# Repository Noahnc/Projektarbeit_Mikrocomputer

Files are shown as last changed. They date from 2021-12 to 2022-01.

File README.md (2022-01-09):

# Projektarbeit Mikrocomputertechnik

In dieser Repository ist sämtlicher Source Code, SQL Statements, Backups und Dokumentationen des Mikrocompuetertechnik-Projekts "Wetterstation".

Grafana Dashboard:
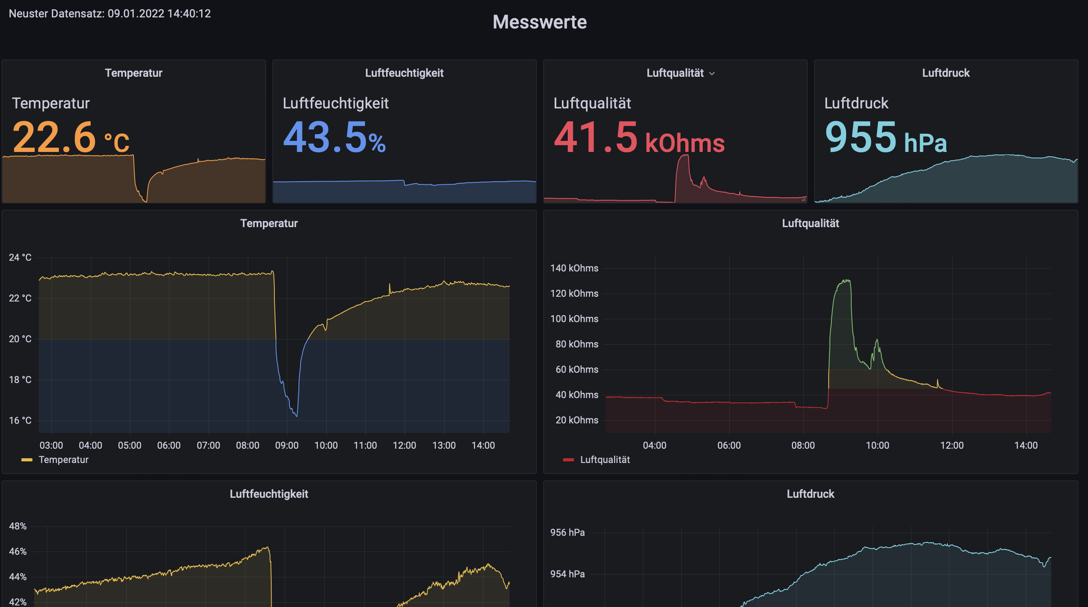
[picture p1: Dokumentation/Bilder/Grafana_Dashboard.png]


Nodered Dashboard:
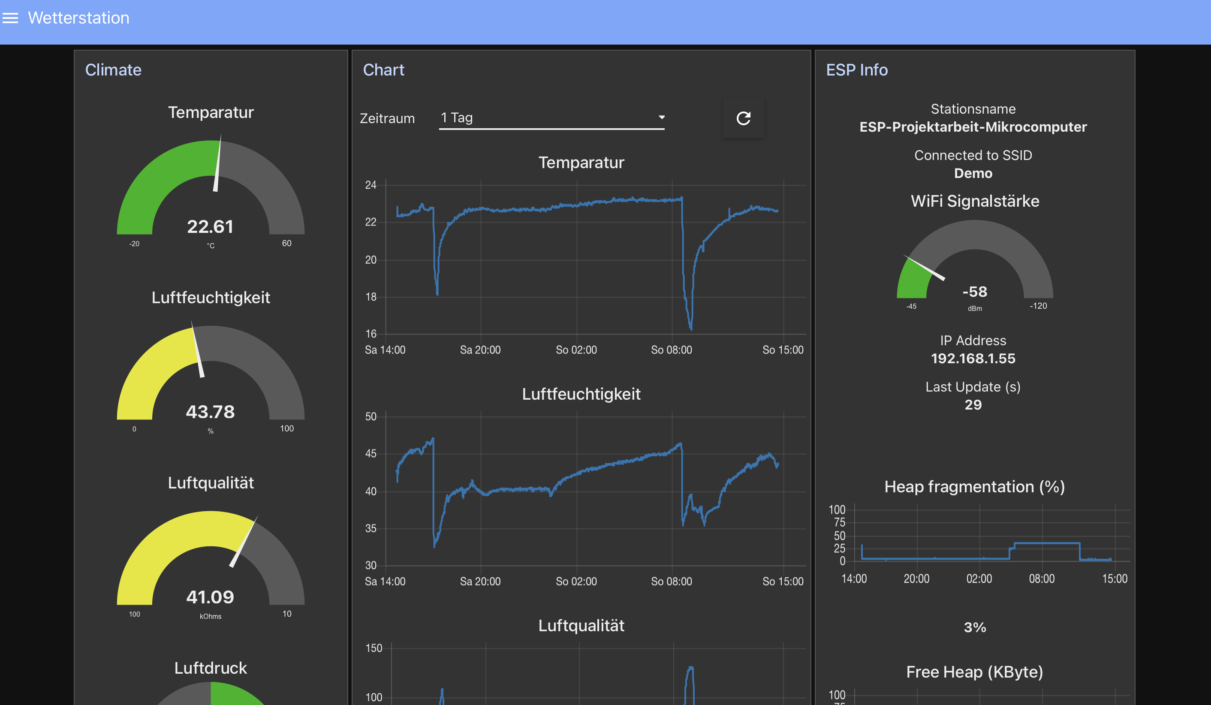
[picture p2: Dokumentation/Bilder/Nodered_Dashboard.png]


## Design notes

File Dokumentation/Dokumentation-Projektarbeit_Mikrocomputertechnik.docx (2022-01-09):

Dokumentation Wetterstation

Projektbezeichnung | Projektarbeit Mikrocomputertechnik
Projektleiter | Noah Canadea / Milan Bursac
Erstellt am | 20.12.2021
Letzte Änderung am | 10.01.2022
Status | abgeschlossen
Aktuelle Version | 1.0

Änderungsverlauf

Nr. | Datum | Version | Geänderte Kapitel | Art der Änderung | Autor | Status
1 | 20.12.2021 | 0.5 | Alle | Erstellung | Noah Canadea | ok
2 | 03.01.2022 | 0.6 | 6, 7, 8 | Ergänzung | Noah Canadea | Ok
3 | 08.01.2022 | 0.7 | Alle | Anpassungen | Noah Canadea | Ok
4 | 09.01.2022 | 1 | Alle | Anpassungen und Ergänzungen | Milan Bursac | Ok

# 1 Schemas

## 1.1 Elektronik Schema ESP (Wetterstation)

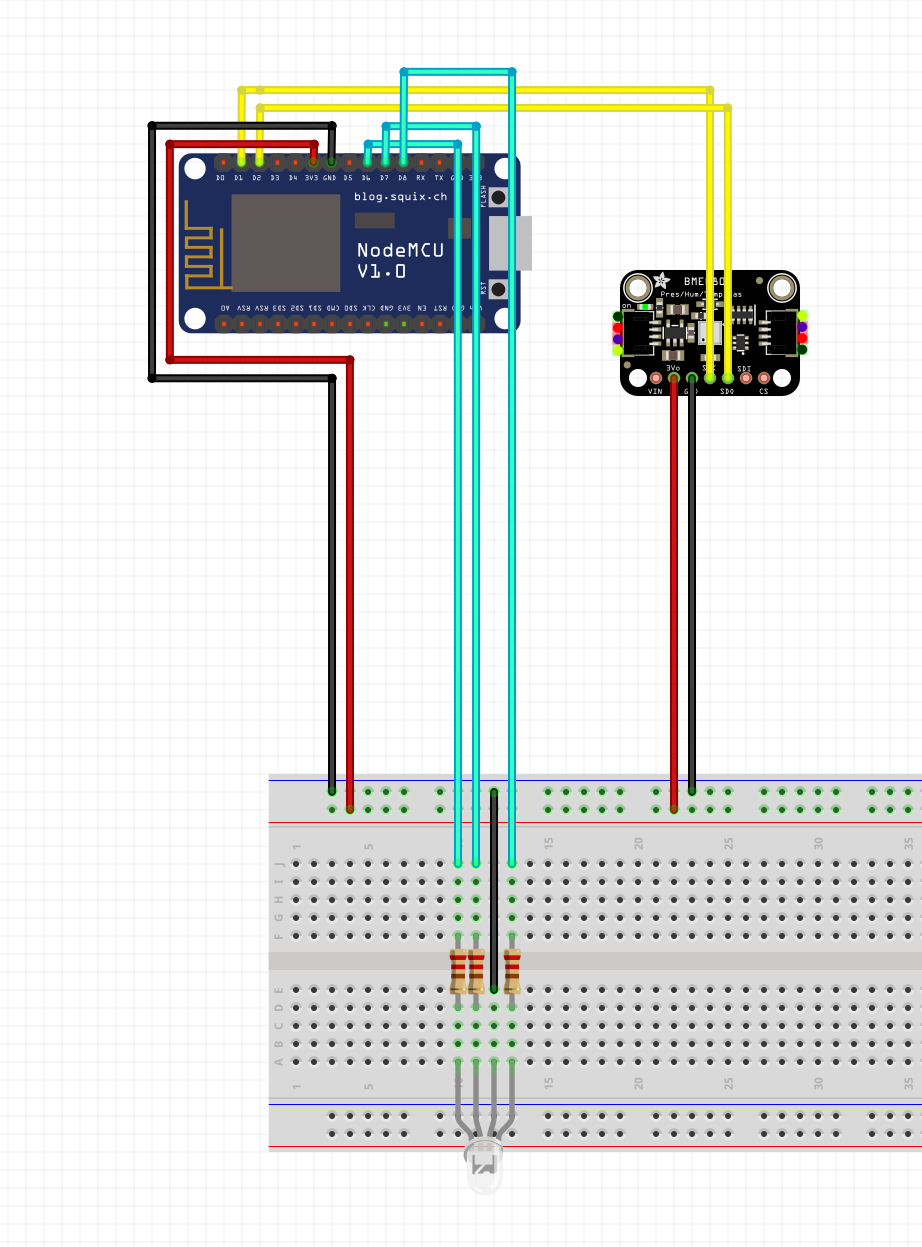
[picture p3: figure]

## 1.2 Aktivitätsdiagramme

### 1.2.1 ESP Code (Wetterstation)

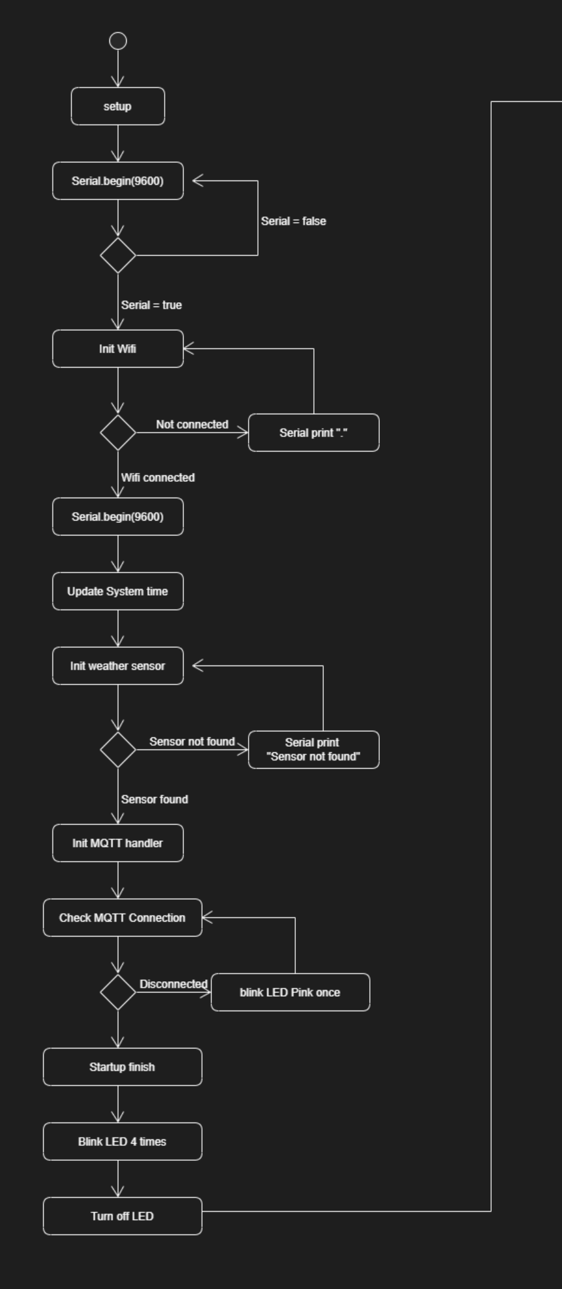
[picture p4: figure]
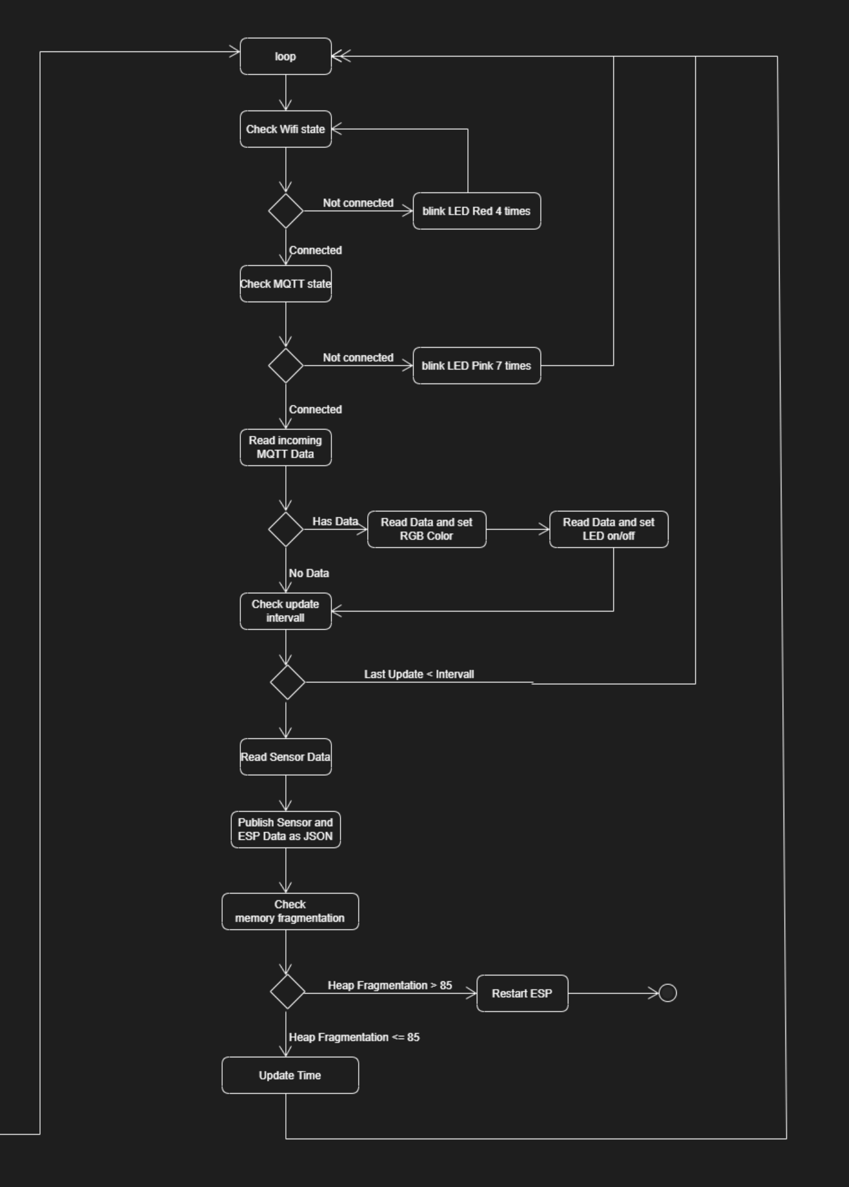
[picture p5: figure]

### 1.2.2 NodeRed (Backend)

Live Data Handler

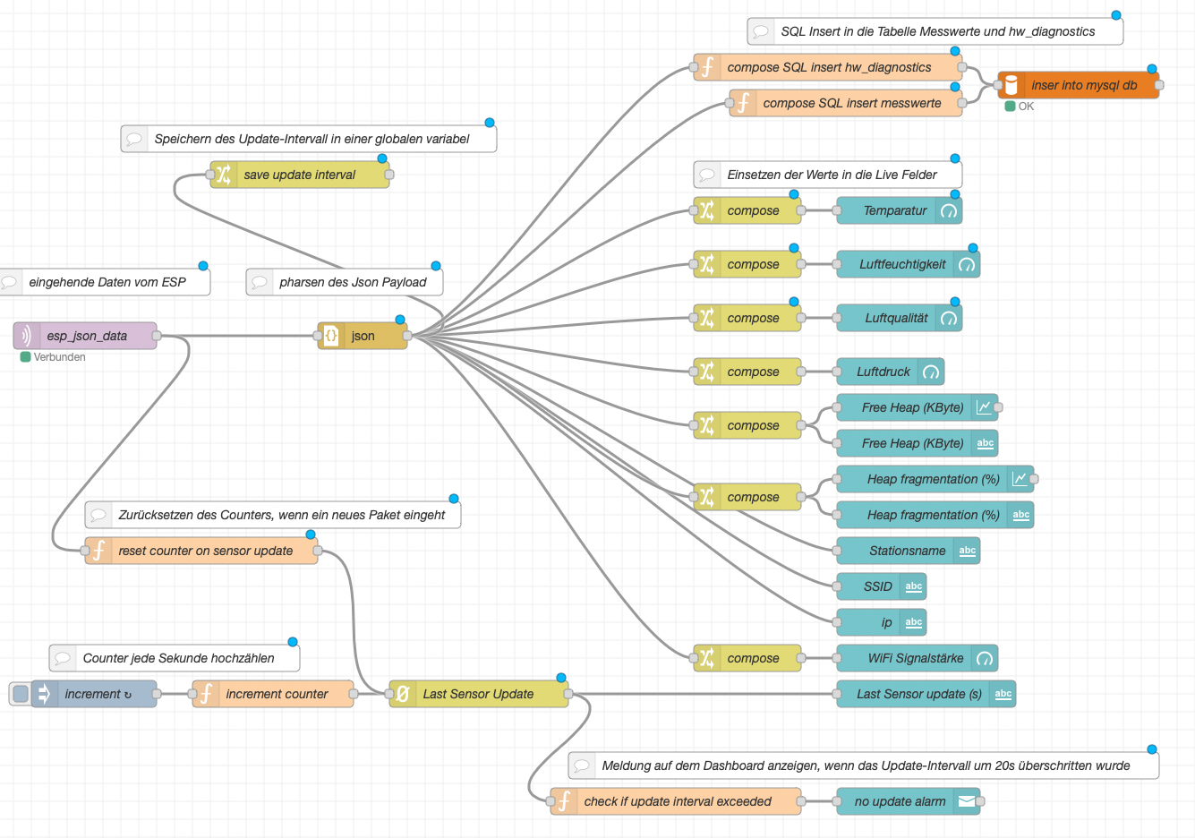
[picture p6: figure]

Hystory Data Handler

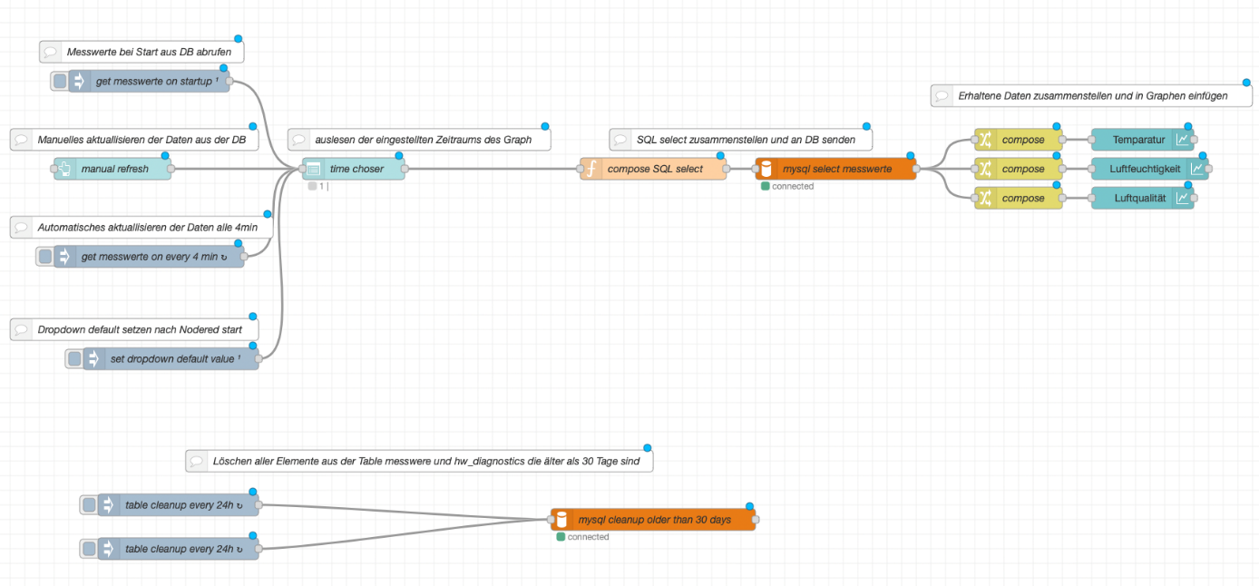
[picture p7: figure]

## 1.3 MySQL Schema

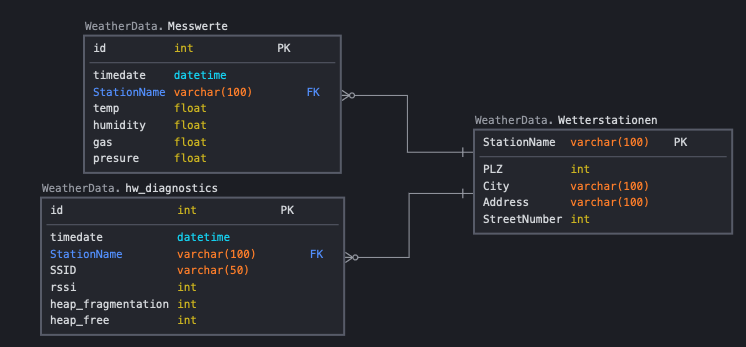
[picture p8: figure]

## 1.4 Prinzipschema Cloud

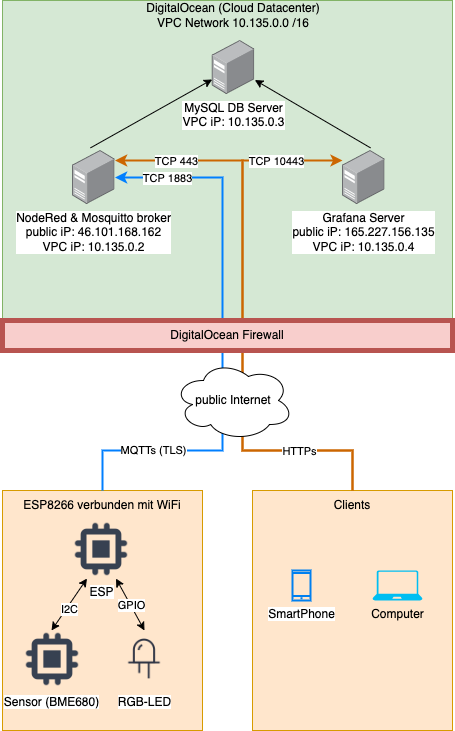
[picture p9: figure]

# 2 Soll – Ist Abgleich

Soll | Ist | Erfüllt
4.1 Erheben folgender Messwerte: - Temperatur - Luftfeuchtigkeit - Luftqualität - Luftdruck | Temperatur, Luftfeuchtigkeit, Luftqualität und Luftdruck werden aufgezeichnet. | JA
4.2 Erheben diverser Metriken der Wetterstation: - iP Adresse - Hostname - Systemzustand - Letztes Update der Station usw. | Die Station sendet diverse Metadaten an den NodeRed Server: - Hostname - Verbundene SSID - WiFi Stärke in RSSI - iP Adresse - Heap Fragmentierung - Freier Heap Speicher | JA
4.3 Persistente Speicherung der Messwerte in der Cloud: Sämtliche, aufgezeichneten Messwerte sollen auf einem zentralen Server in der Cloud für einen definierten Zeitraum gespeichert werden. Hierzu soll eine DB wie Bspw. MySQL verwendet werden, auf welche zu einem späteren Zeitpunkt weitere Systeme für die Auswertung angebunden werden können. | Die Messwerte werden von der Wetterstation als JSON Payload per MQTTs an den NodeRed gesendet. Dieser speichert die Werte anschließend in einem MySQL Server. | JA
4.4 Fehlererkennung: Die Wetterstation soll die Möglichkeit haben, im Falle eines Fehlers (Server Verbindung getrennt, keine Netzwerkverbindung usw.), dies mithilfe einer LED oder eines Displays zu signalisieren. | Verliert die Station die MQTT oder WLAN-Verbindung, wird dies mittels einer RGB LED signalisiert. Je nach Fehler, wird eine andere Farbe verwendet: Rot blinkend: Kein WLAN. Orange blinkend: MQTT Fehler | JA
5.1 Technologien Für die Entwicklung sollen Produkte und Technologien nach aktuellem Stand der Technik eingesetzt werden. Gibt es für eine spezifische Anforderung bereits eine Library, kann diese sofern ausgewiesen verwendet werden. | Sämtlicher Code wurde nach bestem Wissen und Stand der Technik entwickelt. Die verwendeten Module können im Punkt 3 dieses Dokuments entnommen werden. | JA
5.2 Sicherheit Sämtliche Systeme sollen nach aktuellem Stand der Technik abgesichert werden. Verbindungen, welche über das Internet aufgebaut werden, müssen mit Hilfe von SSL/TLS und gültigen Zertifikaten verschlüsselt werden, um ein Mitlesen oder Manipulieren der Daten seitens Dritter zu erschweren. | Das NodeRed UI und Grafana sind über HTTPs mit einem gültiges SSL Zertifikat gesichert. Sämtliche MQTT Kommunikation zwischen Wetterstation und NodeRed (Mosquitto) ist per TLS gesichert. Lediglich mit der Zertifikatsprüfung gibt es noch Probleme, weshalb diese zum aktuellen Zeitpunkt deaktiviert ist. | Teilweise
5.3 Hosting Weil der Kunde die Server nicht lokal betreiben möchte, sollen diese bei einem großen Cloud-Provider gehostet werden. Die Auswahl des Anbieters ist hierbei dem Entwickler überlassen. | Der MySQL Server, Grafana Server und Node-Red Server werden als separate Ubuntu VMs bei DigitalOcean gehostet. | JA
5.4 Erweiterbarkeit Um Erweiterungen zu einem späteren Zeitpunkt zu ermöglichen, müssen sämtliche Software-Module möglichst modular und erweiterbar konzipiert werden. | Der Source-Code der Wetterstation wurde möglichst modular aufgebaut. Für verschiedene Aufgaben wurden eigene Klassen erstellt (Bspw. für das MQTT Handling). Die DB wurde so konzipiert, dass mehrere Wetterstationen gleichzeitig Daten aufzeichnen können. | JA

# 3 Testprotokoll

Test | Erwartetes Ergebnis | Tatsächliches Ergebnis | Erfüllt
Simulieren einer fehlenden WLAN-Verbindung der Wetterstation. | Die LED Blinkt einige Male Rot und pausiert anschliessend. Dies geschieht so lange, bis die WLAN-Verbindung wieder aufgebaut ist. | Die LED Blinkt einige Male Rot und pausiert anschliessend. Dies geschieht so lange, bis die WLAN-Verbindung wieder aufgebaut ist. | Ja
Simulieren einer fehlenden MQTT-Verbindung der Wetterstation. | Die LED Blinkt einige Male Violett und pausiert anschliessend. Dies geschieht so lange, bis die MQTT-Verbindung wieder aufgebaut ist. Auf dem NodeRed Dashboard sollte nach überschreiten des Updateintervall um 20s eine Meldung erscheinen, dass die Station offline ist. | Die LED Blinkt einige Male Violett und pausiert anschliessend. Dies passierte so lange, bis die MQTT-Verbindung wieder hergestellt wurde. Auf dem NodeRed Dashboard ist nach 50s eine Warnmeldung erschienen, dass die Station keine Daten mehr sendet. | Ja
Betreiben der Station für einen längeren Zeitraum, um sicherzustellen, dass diese Stabil läuft. | Die Station sollte ohne Probleme über einen längeren Zeitraum betrieben werden können. Die aufgezeichneten Daten werden hierbei mit dem definierten Updateintervall an den NodeRed gesendet. | Die Station ist Stand 08.01.2022 seit über einer Woche kontinuierlich in Betrieb. Bis jetzt konnten keine Probleme festgestellt werden. Auch das Updateintervall wird zeitlich eingehalten. | Ja
Validieren der Genauigkeit der Messdaten. | Die von der Wetterstation gesammelten Daten sollten relativ genau sein. | Wir haben die vom BME 680 Sensor aufgezeichneten Daten mit einem anderen Produkt (Netatmo) abgeglichen. Die Messwerte sind hierbei ziemlich genau. Bei der Temperatur beträgt der Unterschied Bspw. höchstens 0.2 – 0.4°C. | JA

# 4 Zeitplan

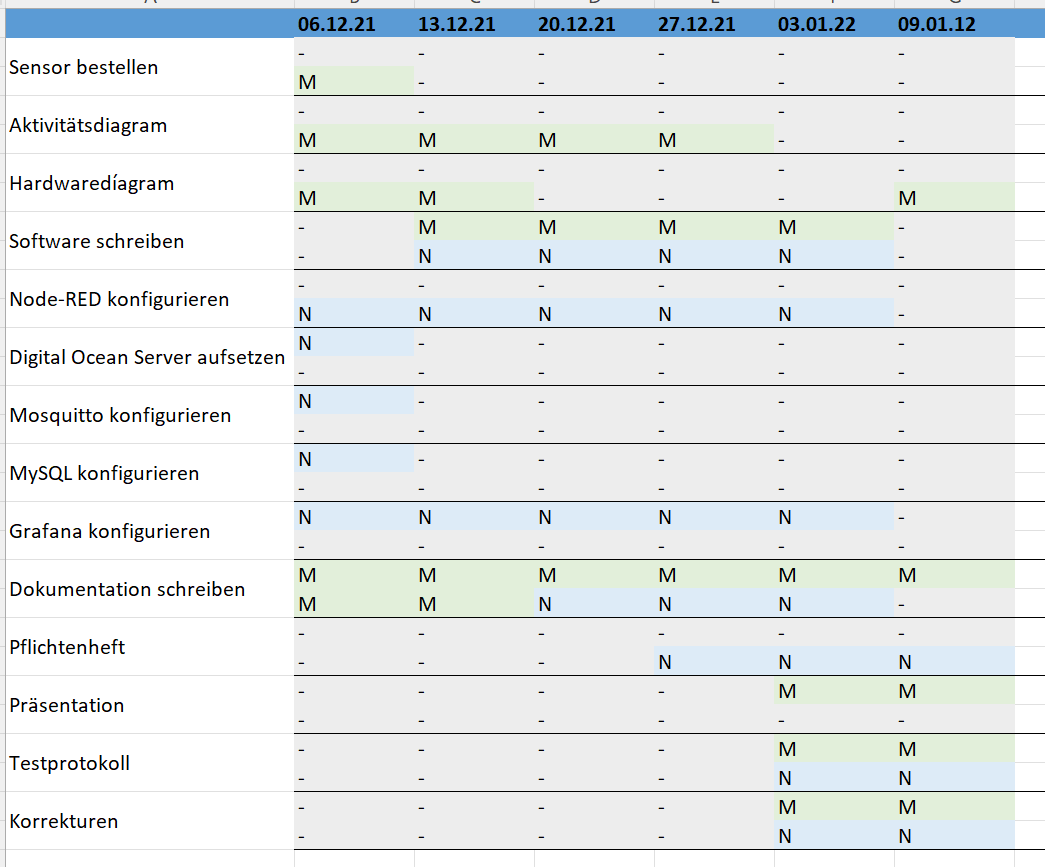
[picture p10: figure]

# 5 Verwendete Produkte und Librarys

## 5.1 Backend / Frontend

- Node-Red (https://nodered.org/): Backend und Frontend UI.
  - Node-red-dashboard (https://flows.nodered.org/node/node-red-dashboard): Diverse UI Elemente.
  - Node-red-node-mysql (https://flows.nodered.org/node/node-red-node-mysql): Verbindungen zum MySQL Server.
  - Node-red-contrib-counter (https://flows.nodered.org/node/node-red-contrib-counter): Baustein welcher einen Counter ausgibt.
- MySQL (https://www.mysql.com/de/): DB Server zur Speicherung der Messwerte.
- Grafana (https://grafana.com/): Visualisierung der MySQL Daten.
  - DynamicText (https://grafana.com/grafana/plugins/marcusolsson-dynamictext-panel/): Modul zur darstellung von dynamischem Text basierend auf SQL Querys.

## 5.2 ESP8266 Wetterstation Librarys

- Adafruit BME680 (https://github.com/adafruit/Adafruit_BME680): Library zum Auslesen der Sensorwerte.
- ESP8266WiFi (https://github.com/esp8266/Arduino/tree/master/libraries/ESP8266WiFi): Library für WLAN und TLS Verbindungen.
- PubSubCLient (https://github.com/knolleary/pubsubclient): Library für MQTT Verbindungen zwischen Node-Red und Wetterstation.
- NTPClient (https://github.com/arduino-libraries/NTPClient): Library für Zeitsync per NTP.
- ArduinoJson (https://github.com/bblanchon/ArduinoJson): Library zum parsen von Daten zu Json Objekten.

## 5.3 ESP8266 Wetterstation Hardware

- NodeMCU ESP8266 (https://www.make-it.ca/nodemcu-details-specifications/): Hauptmodul
- RGB LED (https://components101.com/diodes/rgb-led-pinout-configuration-circuit-datasheet): Status LED
- BME 680 (https://www.bosch-sensortec.com/media/boschsensortec/downloads/datasheets/bst-bme680-ds001.pdf): Wettersensor

# 6 Dashboards Links

- Grafana Dashboard (https://grafana-projektarbeit-mikrocomputer.canadea.ch:10443/d/L2wuqYA7k/wetterstationen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)
- Node-Red Dashboard (https://projektarbeit-mikrocomputer.canadea.ch/ui/)

# 7 Anhang

- Plattform IO Projekt der Wetterstation
- NodeRed Konfiguration
- Grafana Konfiguration
- SQL Statements zur Erstellung der DB
- Pflichtenheft

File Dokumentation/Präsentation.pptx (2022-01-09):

## Abschlussprojekt

Noah & Milan

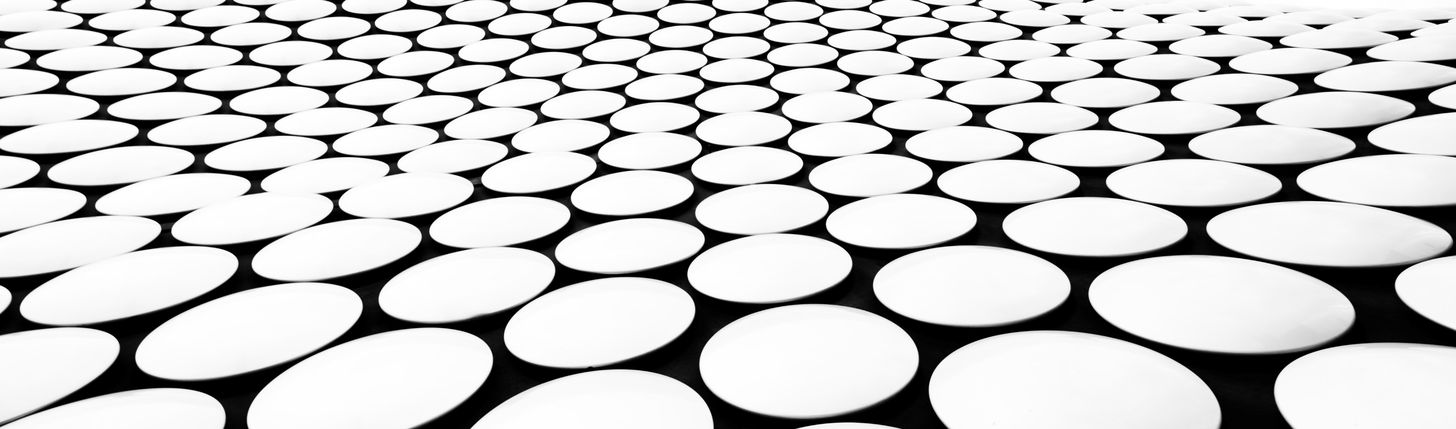
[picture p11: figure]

## Unser Projekt

- Sensordaten (Luftfeuchtigkeit, Temperatur, Luftqualität und Luftdruck) und ESP-Informationen (wie WLAN, Temperatur, Memory, etc.) auf einen Node-RED sowie Grafana Server publishen.
- RGB LED-Steuerung über einen Node-RED Server.

## Aufbau

## Komponenten

1. ESP8266 WiFi
2. BME680 (Sensor)
3. RGB LED
4. 3 Server bei DigitalOcean (Cloud)
5. GitHub für Versioning
6. Teams für Dateiablage

## Prinzipschema


## Fritzing Schema


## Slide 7

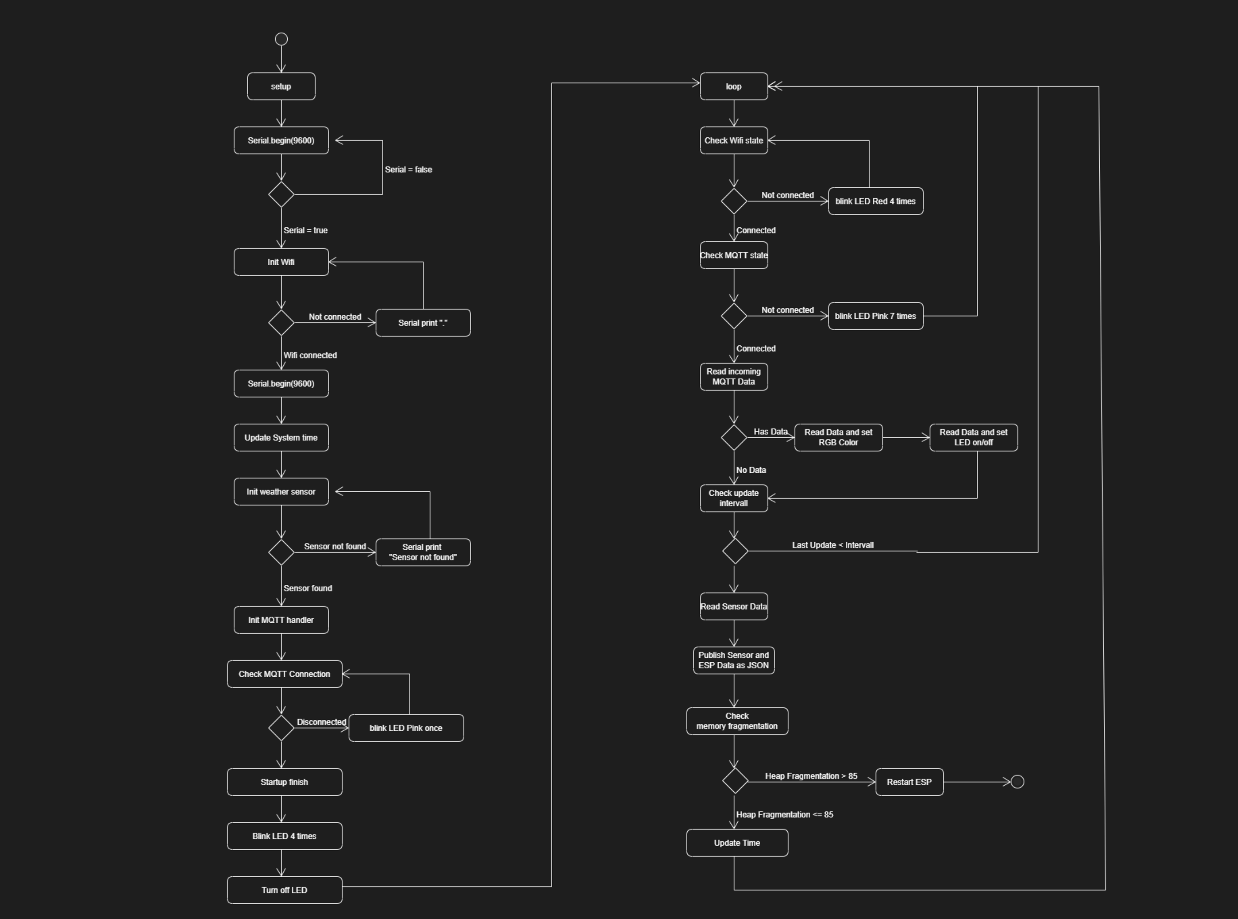
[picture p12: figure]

## MYSQL Schema


## Node-Red: Live-Data Handler

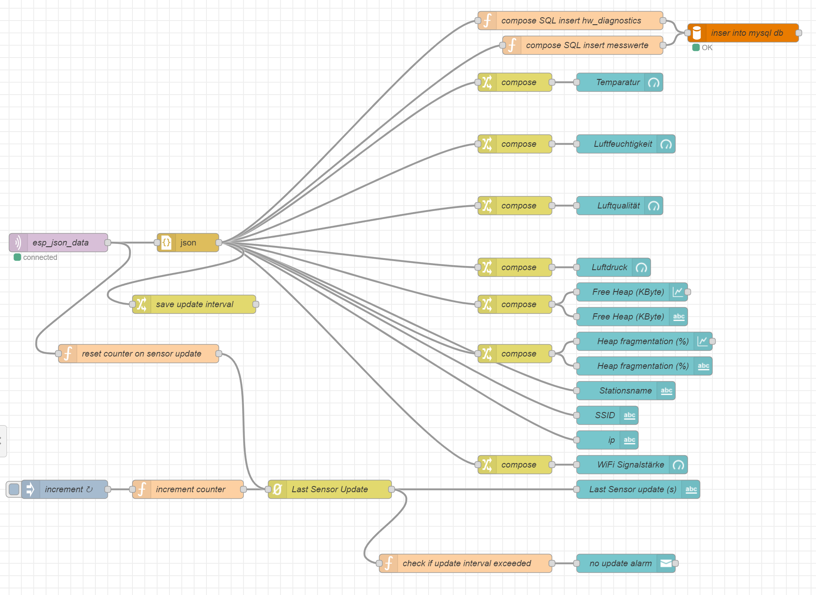
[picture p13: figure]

## Node-Red: History-Data Handler

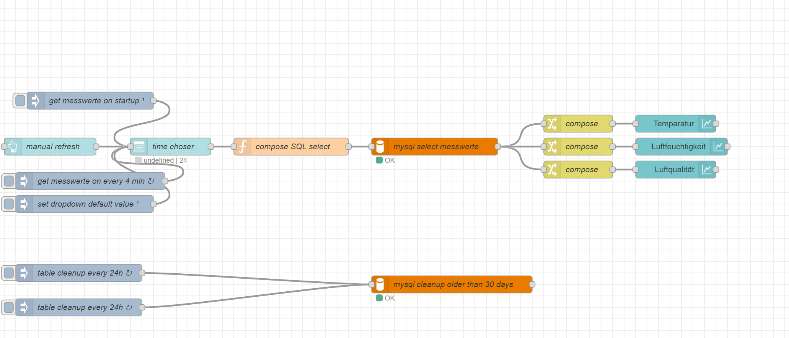
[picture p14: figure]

## Node-Red: LED Handler

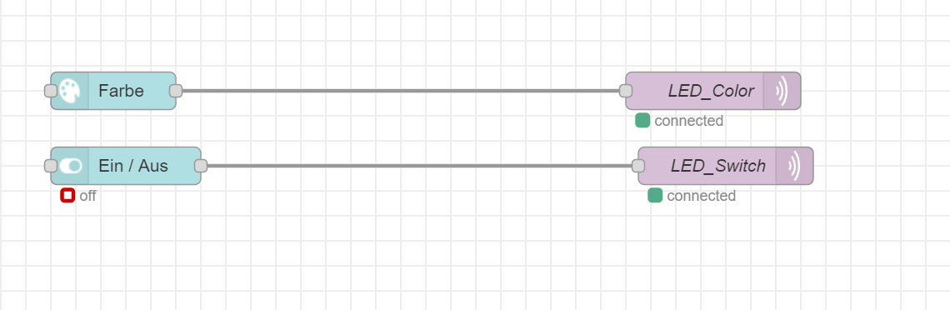
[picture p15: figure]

## Resultat

## Node-Red: RGB LED STeuerung

- Wetterstation Dashboard (canadea.ch) (https://projektarbeit-mikrocomputer.canadea.ch/ui/#!/1?socketid=QfBu8go3oNbt1V-KAAKL)

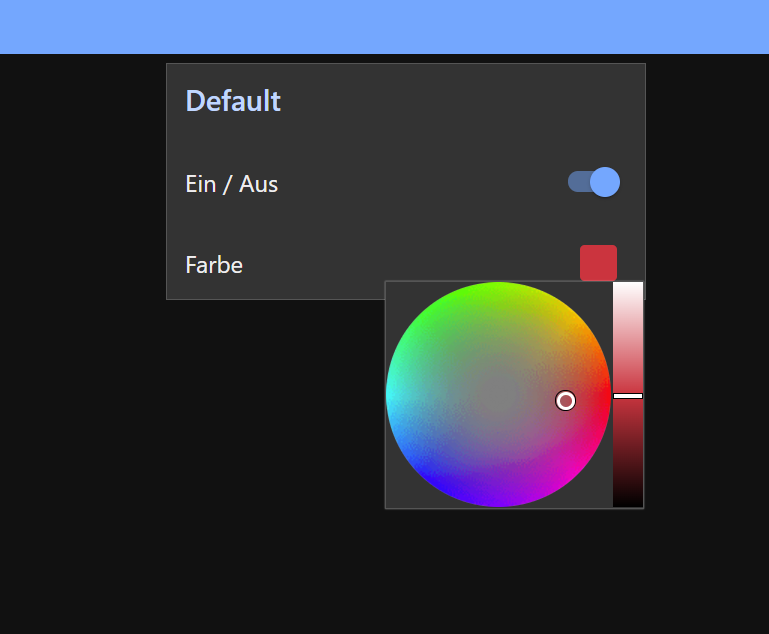
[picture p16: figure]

## Node-red: Sensordaten

- Wetterstation Dashboard (canadea.ch) (https://projektarbeit-mikrocomputer.canadea.ch/ui/#!/0?socketid=QfBu8go3oNbt1V-KAAKL)

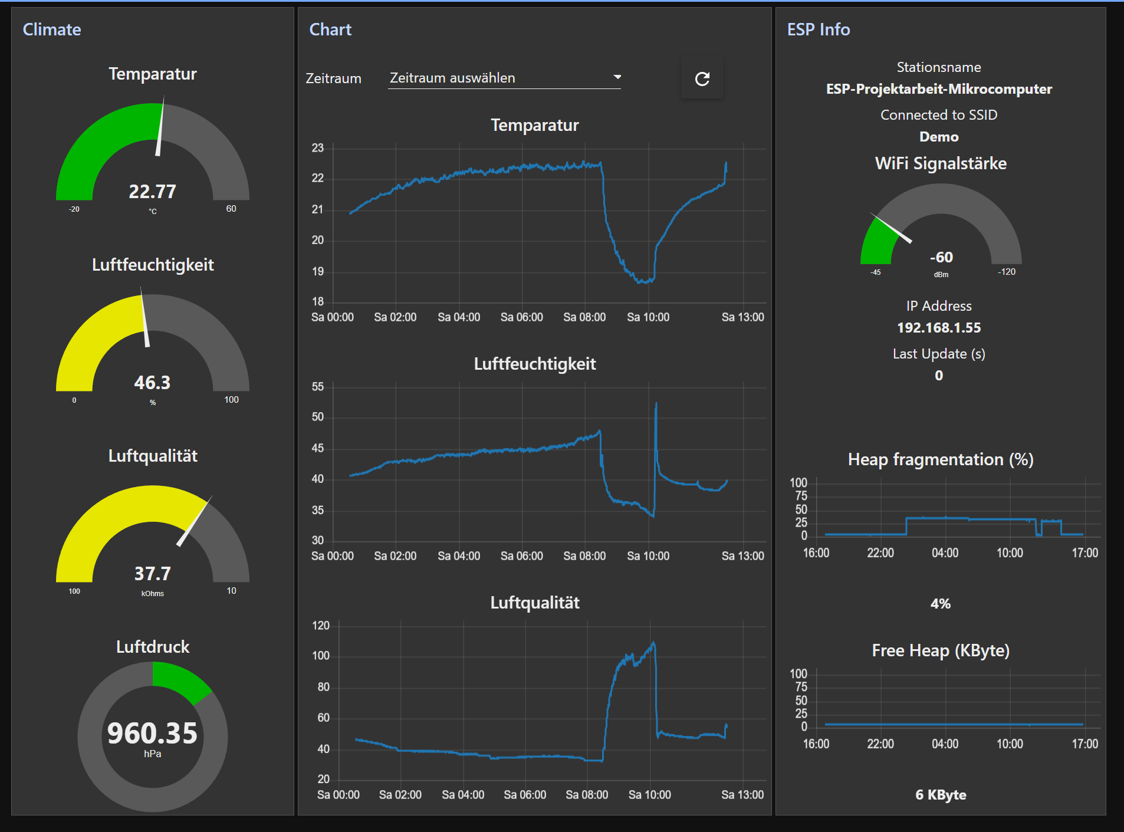
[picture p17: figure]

## Grafana

- Wetterstationen - (https://grafana-projektarbeit-mikrocomputer.canadea.ch:10443/d/L2wuqYA7k/wetterstationen?orgId=1)Grafana (https://grafana-projektarbeit-mikrocomputer.canadea.ch:10443/d/L2wuqYA7k/wetterstationen?orgId=1) (canadea.ch) (https://grafana-projektarbeit-mikrocomputer.canadea.ch:10443/d/L2wuqYA7k/wetterstationen?orgId=1)

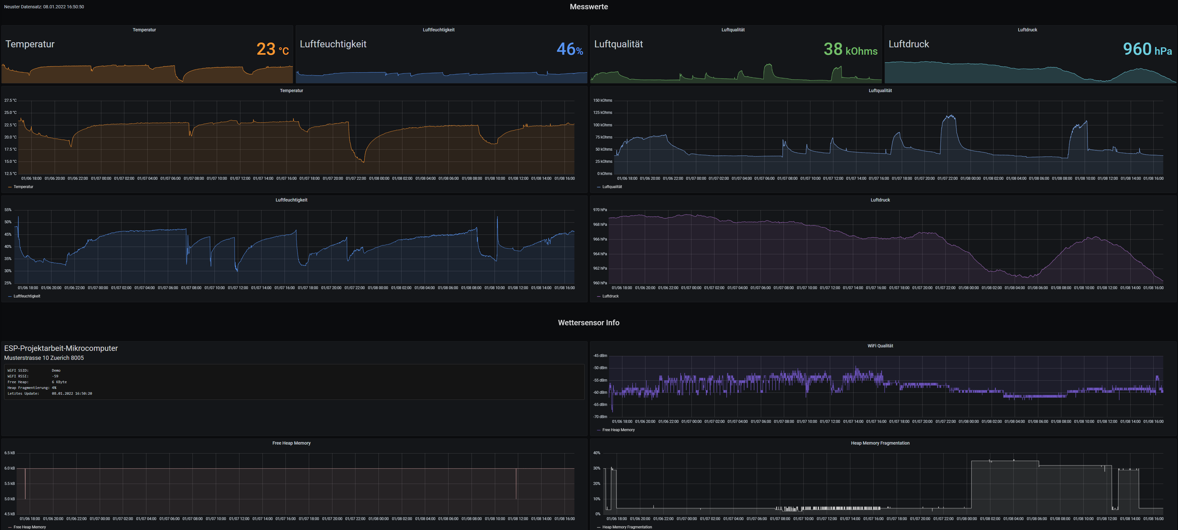
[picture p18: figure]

## Demo

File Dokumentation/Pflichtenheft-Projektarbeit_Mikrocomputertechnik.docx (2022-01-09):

Pflichtenheft Wetterstation

Projektbezeichnung | Projektarbeit Mikrocomputertechnik
Projektleiter | Noah Canadea / Milan Bursac
Erstellt am | 20.12.2021
Letzte Änderung am | 08.01.2022
Status | abgeschlossen
Aktuelle Version | 1.0

Änderungsverlauf

Nr. | Datum | Version | Geänderte Kapitel | Art der Änderung | Autor | Status
1 | 20.12.2021 | 0.5 | Alle | Erstellung | Noah Canadea | ok
2 | 03.01.2022 | 0.9 | 5, 6, 7 | Ergänzung | Noah Canadea | ok
3 | 08.01.2022 | 1.0 | Alle | Ergänzung | Noah Canadea | ok

# 1 Einleitung

## 1.1 Ziel und Zweck des Dokuments

Dieses Pflichtenheft beschreibt die Anforderungen an eine Wetterstation, welche Daten wie die aktuelle Temperatur und Luftfeuchtigkeit sammelt und in einem bestimmten Intervall an einen zentralen Server sendet, wo diese ausgewertet werden können.

## 1.2 Ausgangssituation

Der Kunde betreibt eine Firma mit mehreren Standorten. Um einen besseren Überblick über Daten wie Temperatur, Luftfeuchtigkeit usw. der Büros zu erhalten, wurde vor einem Jahr testweise eine Messstation aufgestellt, welche diese Daten misst und bei der Station anzeigt. Da die Station die gesammelten Daten jedoch nur lokal anzeigen und nicht an ein zentrales System senden kann, hat sich der Kunde dazu entschlossen, ein eigenes System entwickeln zu lassen.

# 2 Konzept

## 2.1 Ziel(e) und Nutzen des Kunden

Ziel dieses Projekts ist es, eine Wetterstation zu entwickeln, welche sämtliche Daten für eine spätere Auswertung an einen zentralen Cloud-Server sendet. Die Messwerte sollen hierbei persistent gespeichert und von anderen Applikationen zugänglich sein. Weiter ist ein UI gewünscht, in welchem die Messwerte und der Zustand der Wetterstation überwacht werden können.

# 3 Funktionale Anforderungen

Folgende funktionale Anforderungen sind seitens Kunde gewünscht.

## 3.1 Erheben folgender Messwerte:

- Temperatur
- Luftfeuchtigkeit
- Luftqualität
- Luftdruck

## 3.2 Erheben diverser Metriken der Wetterstation:

- iP Adresse
- Hostname
- Systemzustand
- Letztes Update der Station
- usw.

## 3.3 Persistente Speicherung der Messwerte in der Cloud:

Sämtliche aufgezeichneten Messwerte sollen auf einem zentralen Server in der Cloud für einen definierten Zeitraum gespeichert werden. Hierzu soll eine DB wie Bspw. MySQL verwendet werden, auf welche zu einem späteren Zeitpunkt weitere Systeme für die Auswertung angebunden werden können.

## 3.4 Fehlererkennung:

Die Wetterstation soll die Möglichkeit haben, im Falle eines Fehlers (Server Verbindung getrennt, keine Netzwerkverbindung usw.), dies mithilfe einer LED oder eines Displays zu signalisieren.

# 4 Nichtfunktionale Anforderungen

Folgende nicht funktionale Anforderungen sind seitens Kunde gewünscht.

## 4.1 Technologien

Für die Entwicklung sollen Produkte und Technologien nach aktuellem Stand der Technik eingesetzt werden. Gibt es für eine spezifische Anforderung bereits eine Library, kann diese, sofern ausgewiesen, verwendet werden.

## 4.2 Sicherheit

Sämtliche Systeme sollen nach aktuellem Stand der Technik abgesichert werden. Verbindungen, welche über das Internet aufgebaut werden, müssen mit Hilfe von SSL/TLS und gültigen Zertifikaten verschlüsselt werden, um ein Mitlesen oder Manipulieren der Daten seitens Dritter zu erschweren.

## 4.3 Hosting

Weil der Kunde die Server nicht lokal betreiben möchte, sollen diese bei einem großen Cloud-Provider gehostet werden. Die Auswahl des Anbieters ist hierbei dem Entwickler überlassen.

## 4.4 Erweiterbarkeit

Um Erweiterungen zu einem späteren Zeitpunkt zu ermöglichen, müssen sämtliche Software-Module möglichst modular und erweiterbar konzipiert werden.

# 5 Rahmenbedingungen

## 5.1 Zeitplan

Das Produkt muss bis spätestens 10.01.2022 in einer ersten Version vorliegen.

## 5.2 Technische Anforderungen

Benötigte Hardware:

- ESP8266 Mikrocomputer als Hauptsystem.
- Bosch Sensor BME680.
- RGB LED
- Widerstände 250 Ohm
- Wireing

Benötigte Server und Software:

- Node-Red Server (Ubuntu 20.04 LTS) als Backend.
- MySQL Server 8 (Ubuntu 20.04 LTS) als DB.

# 6 Liefer- und Abnahmebedingungen

Sämtliche Software und Konfigurationen sollen in elektronischer Form abgegeben werden. Die HW der Wetterstation soll in Form eines Demo-Sample vorliegen. Dieses muss noch nicht einem Serienprodukt entsprechen.

# 7 Anhang

- Technische Dokumentation
- Plattform IO Projekt der Wetterstation
- Node-Red Konfiguration
- SQL Statements zur Erstellung der DB
- Grafana Konfiguration

4 Milan Bursac | Noah Canadea

Pflichtenheft Projektarbeit Mikrocomputertechnik

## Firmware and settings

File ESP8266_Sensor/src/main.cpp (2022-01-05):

/*
########################################################################
# Mikrocomputertechnik Projektarbeit by Noah Canadea and Milan Bursac
########################################################################
#                           Description
#       ESP8266 Code für BME Temparatursensor und RGB LED Steuerung
#
#                    Version 1.0 | 10.01.2021 */

#include <ESP8266WiFi.h>
#include <SPI.h>
#include <Adafruit_Sensor.h>
#include "Adafruit_BME680.h"
#include <Wire.h>
#include <iostream>
#include <string>
#include "00config.h"
#include "RGB_LED_Handler.h"
#include "WiFi_Handler.h"
#include "MQTT_Handler.h"
#include "Sensor_Handler.h"
#include <Arduino.h>
#include "01mqtt_topics.h"
#include <ArduinoJson.h>
#include <NTPClient.h>
#include <WiFiUdp.h>

using namespace config_constants;

double last_sensor_read = 0;
double time_diference;
WiFiUDP ntpUDP;
ADC_MODE(ADC_VCC);

// Erstellen der Objekte
MQTT_Handler mqtt = MQTT_Handler(mosquitto_server, mosquitto_user, mosquitto_pw, ESP_Hostname);
WiFi_Handler wifi = WiFi_Handler(wifi_ssid, wifi_wpa_psk, ESP_Hostname);
Sensor_Handler Weather_Sensor = Sensor_Handler();
NTPClient timeClient(ntpUDP, NTP_Server.c_str(), 3600);
RGB_LED_Handler led = RGB_LED_Handler(led_blue, led_green, led_red);

// Function declaration
String ComposeJsonESPstatus();
void HandleWiFiDisconnect();
void CheckMemoryFragmentation();
void UpdateTime();
void HandleMQTTDisconnect();
void StartupFinished();

// Setup and init
void setup()
{
  Serial.begin(9600);
  while (!Serial)
    ;
  wifi.init();
  timeClient.begin();
  UpdateTime();
  Weather_Sensor.init();
  mqtt.init();
  HandleMQTTDisconnect();
  StartupFinished();
}

// Loop
void loop()
{
  HandleWiFiDisconnect();
  if (mqtt.CheckConnection())
  {
    // Update der
    mqtt.ReadIncoming();

    // Update des Sensors und senden der Daten wenn Update Intervall überschritten
    if ((millis() - last_sensor_read) / 1000 > mqtt_update_interval)
    {
      last_sensor_read = millis();
      Weather_Sensor.readSensorData();
      mqtt.SendData(ESP_JSON_DATA, ComposeJsonESPstatus());
      CheckMemoryFragmentation();
      UpdateTime();
    }
  }
  else
  {
    HandleMQTTDisconnect();
  }
}

String ComposeJsonESPstatus()
{
  String Json_Data;
  StaticJsonDocument<250> doc;

  // Zusammentragen der Daten zu einem Json String
  doc["ssid"] = wifi.getConnectedSSID();
  doc["ip"] = wifi.getNetworkiP();
  doc["rssi"] = wifi.getWiFiRSSI();
  doc["hostname"] = wifi.getHostname();
  doc["temp"] = Weather_Sensor.getTemp();
  doc["humidity"] = Weather_Sensor.getHumidity();
  doc["gas"] = Weather_Sensor.getGas();
  doc["presure"] = Weather_Sensor.getPresure();
  doc["free_heap"] = ESP.getFreeHeap() / 1000;
  doc["heap_fragm"] = ESP.getHeapFragmentation();
  doc["interval"] = mqtt_update_interval;
  serializeJson(doc, Json_Data);

 

  if (debug_mode)
  {
    Serial.println("Composed Json : " + Json_Data);
  }
  return Json_Data;
}

void HandleWiFiDisconnect()
{
  if (wifi.CheckWiFiConnected() == false)
  {
    led.SetLedColor("ff0011");
    int counter = 1;

    while (wifi.CheckWiFiConnected() == false)
    {
      while (counter < 7)
      {
        led.TurnOnLED();
        delay(100);
        led.TurnOffLed();
        delay(100);
        counter++;
      }
      delay(5000);
      counter = 1;
    }
  }
}

void HandleMQTTDisconnect()
{
  if (mqtt.CheckConnection() == false)
  {
    led.SetLedColor("ff00bf");
    int counter = 1;

    while (mqtt.CheckConnection() == false)
    {
      while (counter < 7)
      {
        led.TurnOnLED();
        delay(100);
        led.TurnOffLed();
        delay(100);
        counter++;
      }
      mqtt.reconnect();
      counter = 1;
    }
  }
}

void CheckMemoryFragmentation()
{
  if (ESP.getHeapFragmentation() > 85)
  {
    Serial.println("Heap fragmentation is to high, restart ESP board");
    ESP.restart();
  }
}

void UpdateTime()
{
  timeClient.update();
  if (debug_mode)
  {
    Serial.println("Aktuelle Zeit: " + timeClient.getFormattedTime());
  }
}

void StartupFinished()
{
  led.SetLedColor("00FF00");
  int counter = 1;
  while (counter < 4)
  {
    led.TurnOnLED();
    delay(100);
    led.TurnOffLed();
    delay(100);
    counter++;
  }

  led.TurnOnLED();
  delay(2000);
  led.TurnOffLed();
}

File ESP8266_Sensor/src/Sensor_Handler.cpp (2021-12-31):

/* 
########################################################################
#                          Sensor Handler
########################################################################
#                           Description
#         Handelt das Auslesen eines BME680 Climate Sensors
*/

#include <SPI.h>
#include <Adafruit_Sensor.h>
#include "Adafruit_BME680.h"
#include <Wire.h>
#include <iostream>
#include "Sensor_Handler.h"
#include "00config.h"

using namespace config_constants;

void Sensor_Handler::init()
{
    if (debug_mode)
    {
        Serial.println("BME680 async test");
    }

    if (!bme.begin())
    {
        if (debug_mode)
        {
            Serial.println("Could not find a valid BME680 sensor, check wiring!");
        }
        while (1)
            ;
    }

    // Set up oversampling and filter initialization
    bme.setTemperatureOversampling(BME680_OS_8X);
    bme.setHumidityOversampling(BME680_OS_2X);
    bme.setPressureOversampling(BME680_OS_4X);
    bme.setIIRFilterSize(BME680_FILTER_SIZE_3);
    bme.setGasHeater(320, 150); // 320*C for 150 ms
}

bool Sensor_Handler::readSensorData()
{
    // Server
    unsigned long endTime = bme.beginReading();
    if (endTime == 0)
    {
        if (debug_mode)
        {
            Serial.println("Failed to begin reading :(");
        }
        return false;
    }

    if (debug_mode)
    {
        Serial.print("Sensor Reading started at ");
        Serial.print(millis());

        Serial.print(" and will finish at ");
        Serial.println(endTime);
    }

    delay(50);
    if (!bme.endReading())
    {
        if (debug_mode)
        {
            Serial.println("Failed to complete reading :(");
        }

        return false;
    }

    if (debug_mode)
    {
        Serial.print("Reading completed at ");
        Serial.println(millis());
    }

    // Temperature
    if (debug_mode)
    {
        Serial.print("Temperature = ");
        Serial.print(bme.temperature);
        Serial.println(" *C");
    }
    Temparature = "";
    Temparature += bme.temperature;

    // Preassure
    if (debug_mode)
    {
        Serial.print("Pressure = ");
        Serial.print(bme.pressure / 100.0);
        Serial.println(" hPa");
    }
    Presure = "";
    Presure += (bme.pressure / 100.0);

    // Humidity
    if (debug_mode)
    {
        Serial.print("Humidity = ");
        Serial.print(bme.humidity);
        Serial.println(" %");
    }
    Humidity = "";
    Humidity += bme.humidity;

    // Gas
    if (debug_mode)
    {
        Serial.print("Gas = ");
        Serial.print(bme.gas_resistance / 1000.0);
        Serial.println(" KOhms");
    }
    Gas = "";
    Gas += (bme.gas_resistance / 1000.0);

    // Altitude
    if (debug_mode)
    {
        Serial.print("Approx. Altitude = ");
        Serial.print(bme.readAltitude(SEALEVELPRESSURE_HPA));
        Serial.println(" m");
    }
    Altitude = "";
    Altitude += bme.readAltitude(SEALEVELPRESSURE_HPA);

    Serial.println();
    delay(2000);
    return true;
}

float Sensor_Handler::getTemp()
{
    return Temparature.toFloat();
}

float Sensor_Handler::getPresure()
{
    return Presure.toFloat();
}

float Sensor_Handler::getHumidity()
{
    return Humidity.toFloat();
}
float Sensor_Handler::getGas()
{
    return Gas.toFloat();
}

float Sensor_Handler::getAltitude()
{
    return Altitude.toFloat();
}
